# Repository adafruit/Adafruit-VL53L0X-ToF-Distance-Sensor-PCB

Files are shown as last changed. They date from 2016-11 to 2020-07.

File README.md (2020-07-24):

# PCB files for the Adafruit VL53L0X ToF Distance Sensor

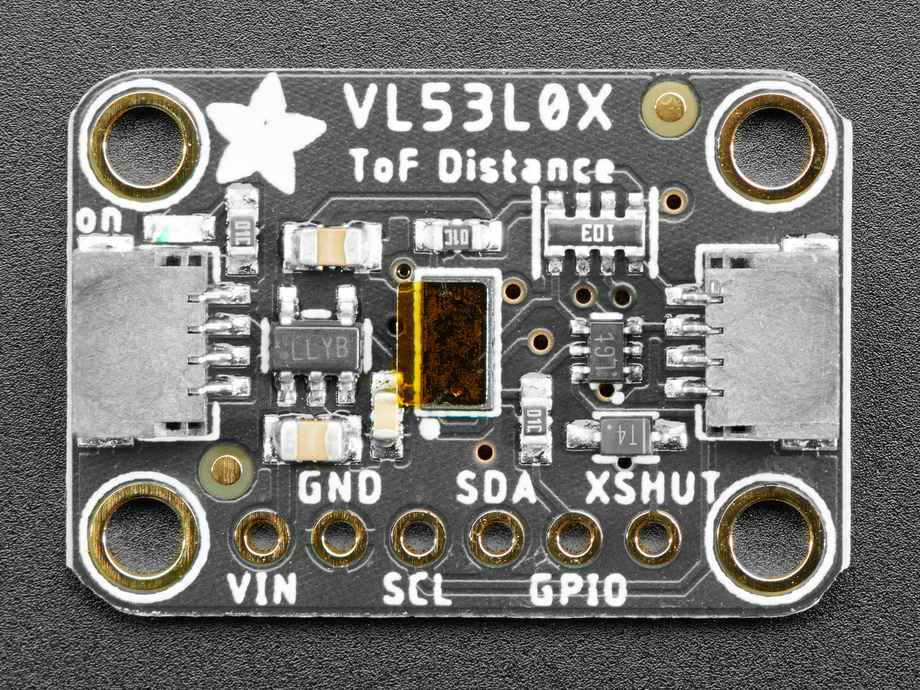
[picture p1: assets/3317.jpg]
<a href="http://www.adafruit.com/products/3317"><br/></a>
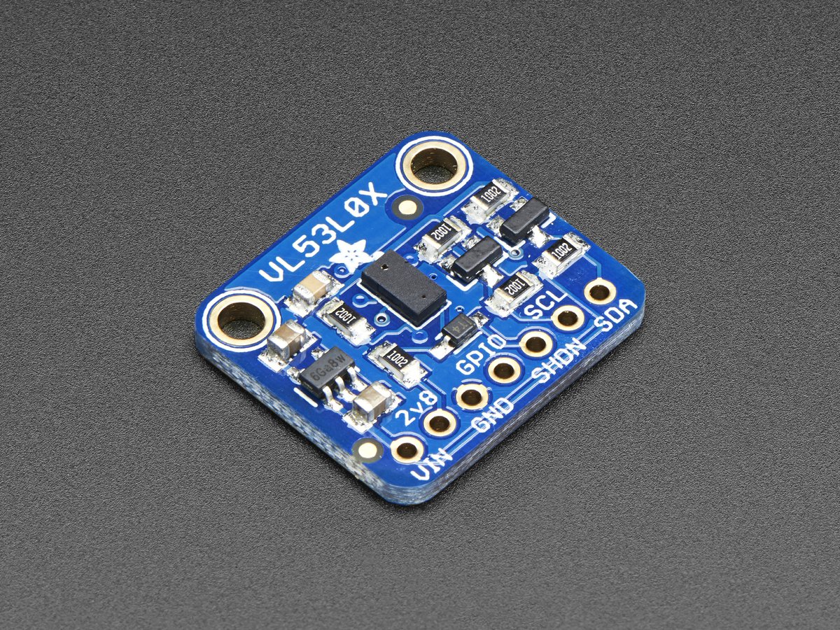
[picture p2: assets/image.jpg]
<a href="http://www.adafruit.com/products/3317"><br/>Click here to purchase one from the Adafruit shop</a>

__Format is EagleCAD schematic and board layout__

The __VL53L0X__ is a *Time of Flight* distance sensor like no other you've used! The sensor contains a very tiny invisible laser source, and a matching sensor. The VL53L0X can detect the "time of flight", or how long the light has taken to bounce back to the sensor. Since it uses a very narrow light source, it is good for determining distance of only the surface directly in front of it. Unlike sonars that bounce ultrasonic waves, the 'cone' of sensing is very narrow. Unlike IR distance sensors that try to measure the amount of light bounced, the VL53L0x is much more precise and doesn't have linearity problems or 'double imaging' where you can't tell if an object is very far or very close.

This is the 'big sister' of the [VL6180X ToF sensor](https://www.adafruit.com/products/3316), and can handle about 50mm to 1200mm of range distance. If you need a smaller/closer range, check out the VL6180X which can measure 5mm to 200mm and also contains a light sensor.

The sensor is small and easy to use in any robotics or interactive project. Since it needs 2.8V power and logic we put the little fellow on a breakout board with a regulator and level shifting. You can use it with any 3-5V power or logic microcontroller with no worries. Each order comes with a small piece of header. Solder the header onto your breakout board with your iron and some solder and wire it up for instant distance-sensing-success!

Communicating to the sensor is done over I2C with an API written by ST, so its not too hard to port it to your favorite microcontroller. We've written a wrapper library for Arduino so you can use it with any of your Arduino-compatible boards.

[Check out our tutorial for code, schematics, diagrams and more!](https://learn.adafruit.com/adafruit-vl53l0x-micro-lidar-distance-sensor-breakout)

## License

Adafruit invests time and resources providing this open source design, 
please support Adafruit and open-source hardware by purchasing 
products from Adafruit!

Designed by Adafruit Industries.  
Creative Commons Attribution, Share-Alike license, check license.txt for more information
All text above must be included in any redistribution

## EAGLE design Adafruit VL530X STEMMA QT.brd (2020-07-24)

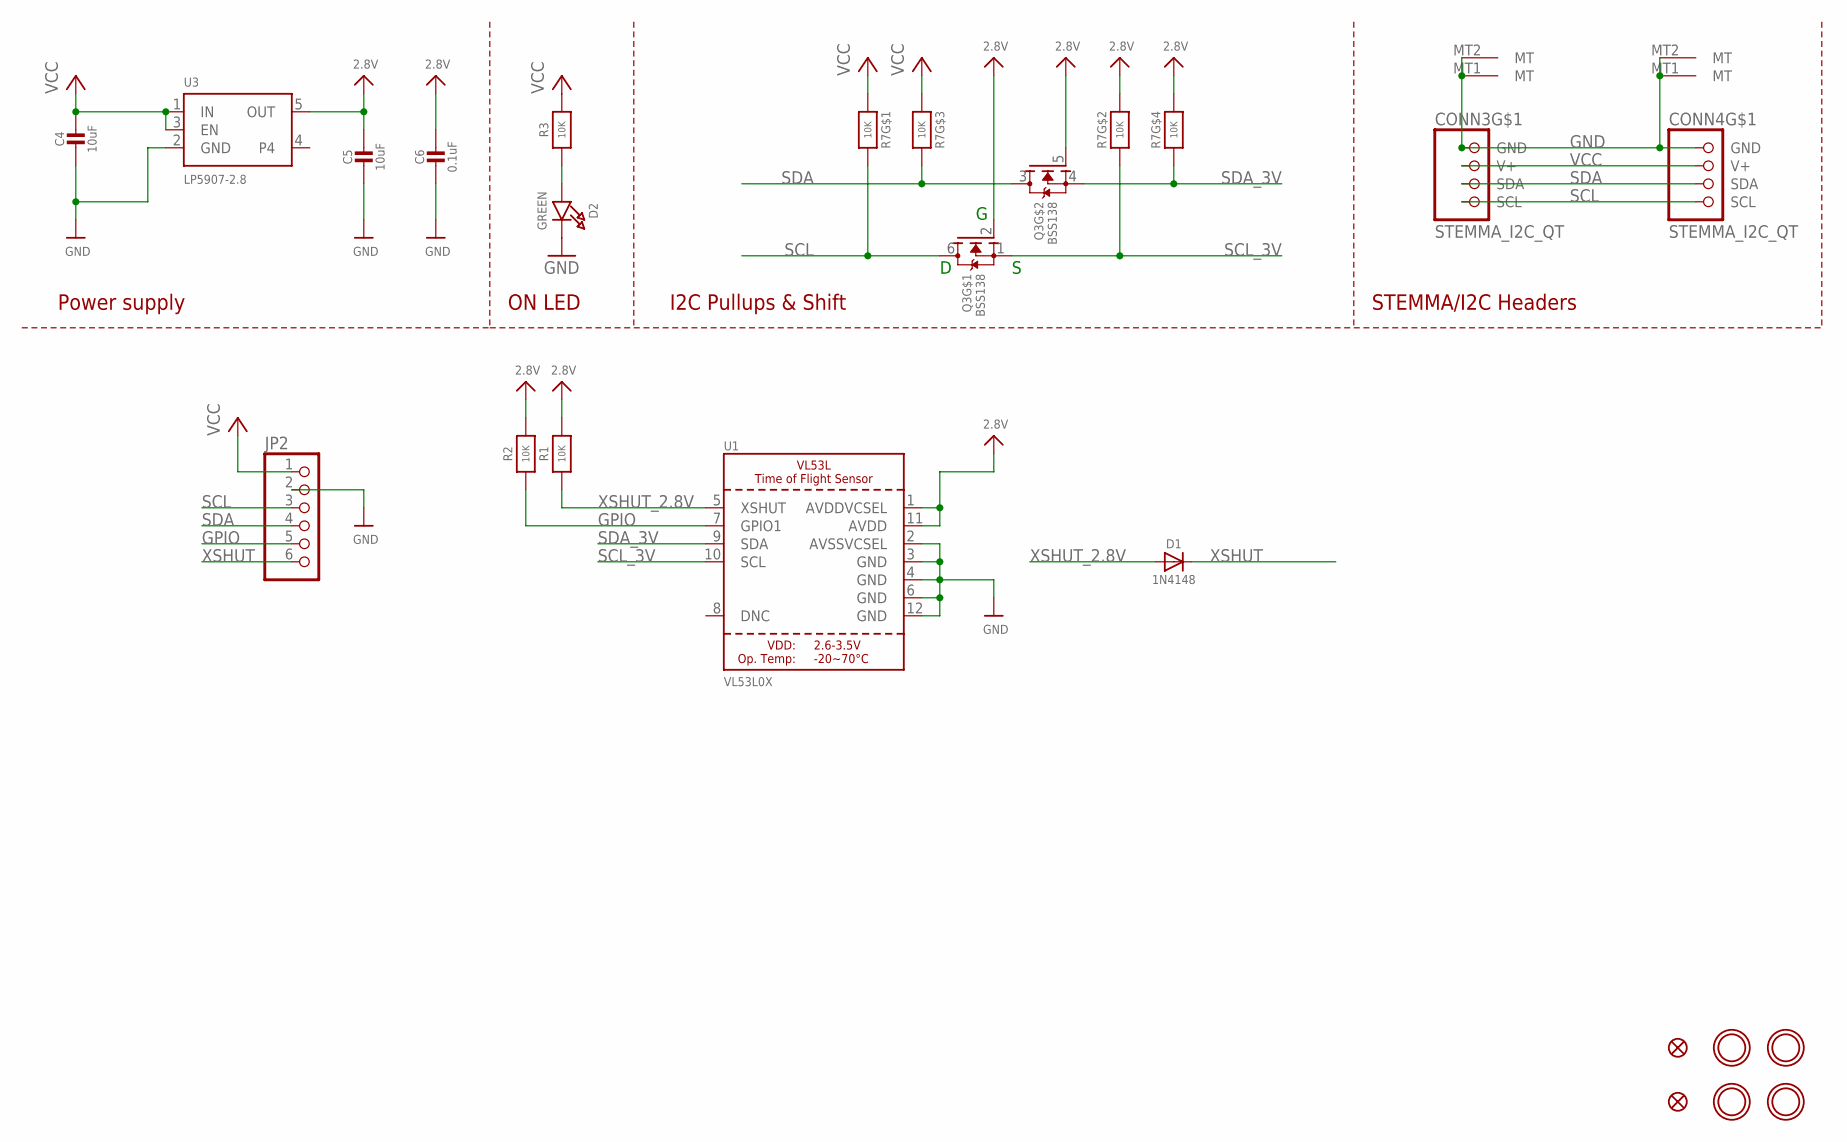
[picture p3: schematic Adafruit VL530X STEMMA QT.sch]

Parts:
C4, C5: 10uF; 0805-NO
C6: 0.1uF; 0603-NO
CONN3, CONN4: STEMMA_I2C_QT; JST_SH4
D1: 1N4148; SOD-323
D2: GREEN; CHIPLED_0603_NOOUTLINE
FID1, FID4: FIDUCIAL_1MM
JP2: HEADER-1X670MIL; 1X06_ROUND_70
Q3: BSS138; SOT363
R1, R2, R3: 10K; 0603-NO
R7: 10K; RESPACK_4X0603
U1: VL53L0X; LGA12_ST
U3: LP5907-2.8; SOT23-5
U$30, U$31, U$33, U$34: MOUNTINGHOLE2.5; MOUNTINGHOLE_2.5_PLATED

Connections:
2.8V: C5.1, C6.1, Q3.2 (G), Q3.5 (G), R1.2, R2.2, R7.2 (1), R7.4 (1), U1.1 (AVDDVCSEL), U1.11 (AVDD), U3.5 (OUT)
GND: C4.2, C5.2, C6.2, CONN3.1 (GND), CONN3.MT1 (MT), CONN3.MT2 (MT), CONN4.1 (GND), CONN4.MT1 (MT), CONN4.MT2 (MT), D2.C, JP2.2, U1.2 (AVSSVCSEL), U1.3 (GND), U1.4 (GND), U1.6 (GND), U1.12 (GND), U3.2 (GND)
GPIO: JP2.5, R2.1, U1.7 (GPIO1)
unnamed: D2.A, R3.1
SCL: CONN3.4 (SCL), CONN4.4 (SCL), JP2.3, Q3.6 (D), R7.8 (2)
SCL_3V: Q3.1 (S), R7.7 (2), U1.10 (SCL)
SDA: CONN3.3 (SDA), CONN4.3 (SDA), JP2.4, Q3.3 (D), R7.6 (2)
SDA_3V: Q3.4 (S), R7.5 (2), U1.9 (SDA)
VCC: C4.1, CONN3.2 (V+), CONN4.2 (V+), JP2.1, R3.2, R7.1, R7.3 (1), U3.1 (IN), U3.3 (EN)
XSHUT: D1.C, JP2.6
XSHUT_2.8V: D1.A, R1.1, U1.5 (XSHUT)

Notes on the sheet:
I2C Pullups & Shift
STEMMA/I2C Headers
ON LED
Power supply

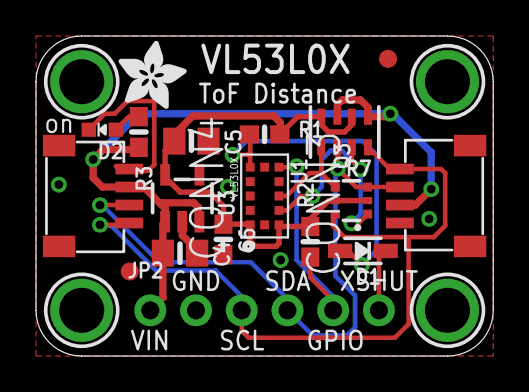
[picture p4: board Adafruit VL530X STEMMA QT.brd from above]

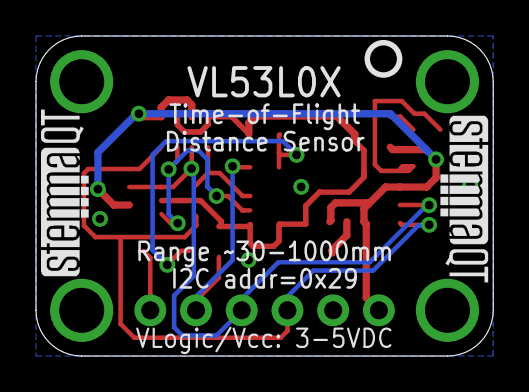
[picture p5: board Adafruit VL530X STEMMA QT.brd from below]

Board: 2 copper layers, 25.4 x 17.8 mm, 25 parts (3 on the bottom side), 11 nets.

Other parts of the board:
U$36: ADAFRUIT_3.5MM
U$37: PCBFEAT-REV-040
U$38, U$39: STEMMAQT

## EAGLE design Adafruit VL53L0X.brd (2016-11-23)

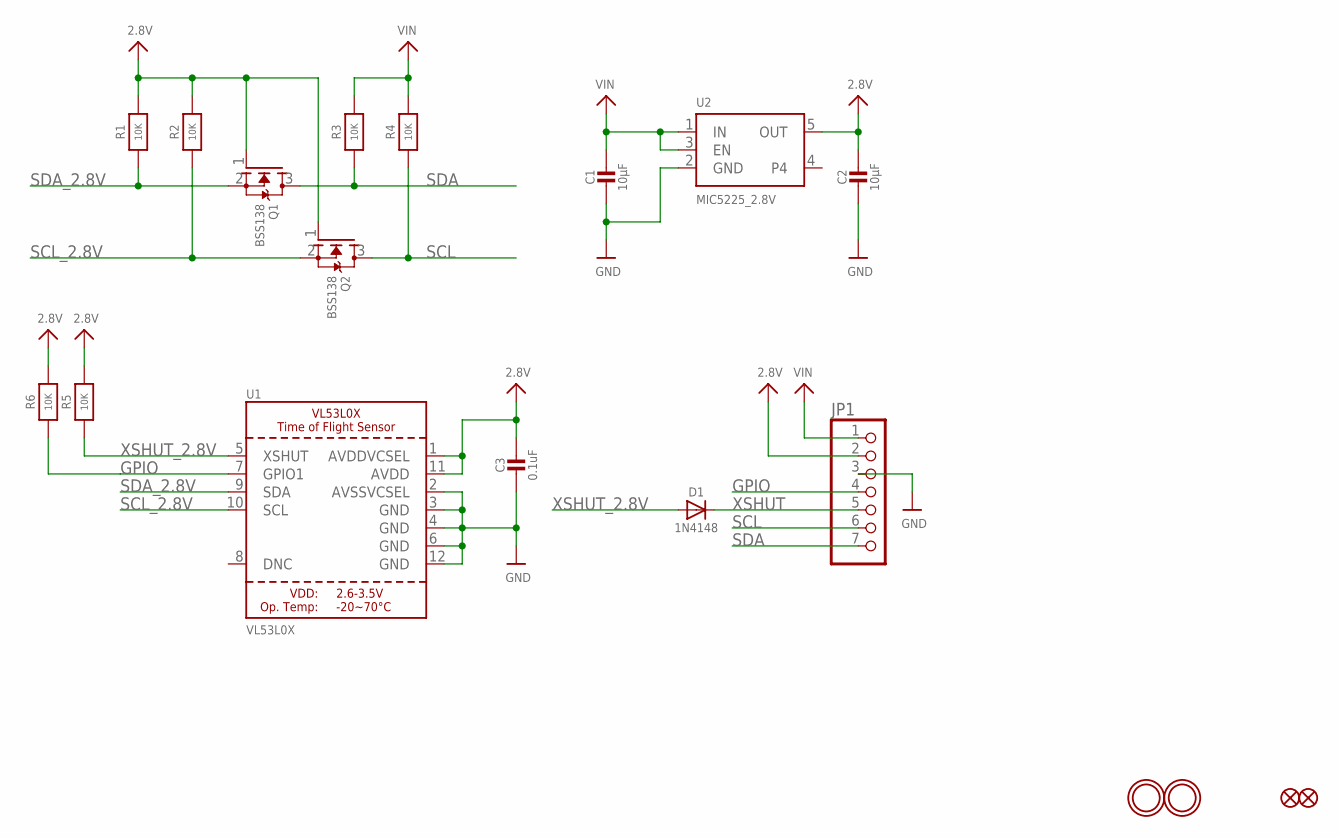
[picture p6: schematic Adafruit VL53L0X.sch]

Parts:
C1, C2: 10µF; 0805-NO
C3: 0.1uF; 0805-NO
D1: 1N4148; SOD-323
FID2, FID3: FIDUCIAL""; FIDUCIAL_1MM
JP1: HEADER-1X770MIL; 1X07_ROUND_70
Q1, Q2: BSS138; SOT23-WIDE
R1, R2, R3, R4, R5, R6: 10K; 0805-NO
U1: VL53L0X; LGA12_ST
U2: MIC5225_2.8V; SOT23-5
U$13, U$14: MOUNTINGHOLE2.5; MOUNTINGHOLE_2.5_PLATED

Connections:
2.8V: C2.1, C3.1, JP1.2, Q1.1 (G), Q2.1 (G), R1.2, R2.2, R5.2, R6.2, U1.1 (AVDDVCSEL), U1.11 (AVDD), U2.5 (OUT)
GND: C1.2, C2.2, C3.2, JP1.3, U1.2 (AVSSVCSEL), U1.3 (GND), U1.4 (GND), U1.6 (GND), U1.12 (GND), U2.2 (GND)
GPIO: JP1.4, R6.1, U1.7 (GPIO1)
SCL: JP1.6, Q2.3 (D), R4.1
SCL_2.8V: Q2.2 (S), R2.1, U1.10 (SCL)
SDA: JP1.7, Q1.3 (D), R3.1
SDA_2.8V: Q1.2 (S), R1.1, U1.9 (SDA)
VIN: C1.1, JP1.1, R3.2, R4.2, U2.1 (IN), U2.3 (EN)
XSHUT: D1.C, JP1.5
XSHUT_2.8V: D1.A, R5.1, U1.5 (XSHUT)

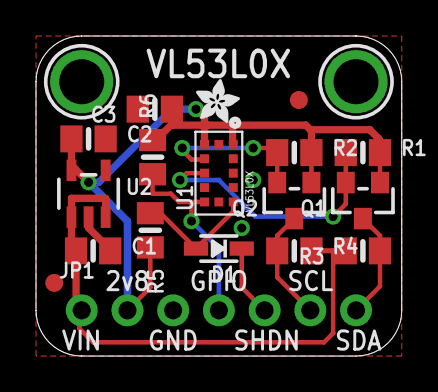
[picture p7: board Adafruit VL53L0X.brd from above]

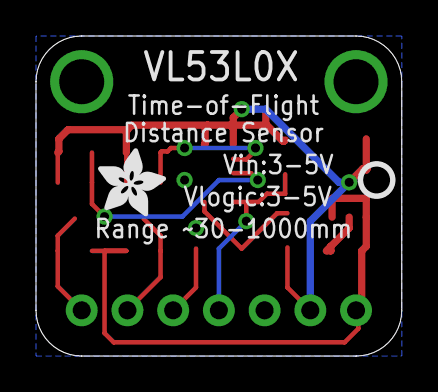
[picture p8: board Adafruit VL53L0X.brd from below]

Board: 2 copper layers, 20.3 x 17.8 mm, 22 parts (2 on the bottom side), 10 nets.

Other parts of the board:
U$12: PCBFEAT-REV-040
U$15: ADAFRUIT_3.5MM
U$18: ADAFRUIT_2.5MM

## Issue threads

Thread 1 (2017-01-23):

Footprint for VL53L0X?

LukeL99, 2017-01-23:
I'm implementing a custom design using the VL53L0X, and I can't find a footprint to use for it. I checked your design, and saw it was referenced from the microbuilder library, but I can't find it in the version of the microbuilder library I found online, nor in the Adafruit eagle library. Can you provide the part definition files somewhere?

Thanks!

ladyada, 2017-01-23:
try http://slopjong.de/2012/12/06/eagle-extract-a-symbol-from-a-project-to-a-library/ !

LukeL99, 2017-01-23:
Didn't know you could do that - worked great. Thanks for the fast response!

For anyone trying to do this in the future, open the board or schematic, and navigate to:

File > Export > Libraries

The ULP will only give you the footprint or the symbol, depending on whether you're on schematic or layout. Exporting will give you the full libraries.

Closed 2017-01-23.

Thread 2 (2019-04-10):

Typo in the reference to product page.

AlvaroHermida, 2019-04-10:
The reference should be:
https://www.adafruit.com/product/3317
instead of the current:
https://www.adafruit.com/product/3177

ladyada, 2019-04-10:
@hoffmanjan

hoffmannjan, 2019-05-15:
https://github.com/adafruit/Adafruit-VL53L0X-ToF-Distance-Sensor-PCB/pull/4

added readme + image + requested URL fix + license, please close when merged

ladyada, 2019-05-15:
we cleaned this repo :)

Closed 2019-05-15.

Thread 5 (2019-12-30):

False triggers in sunlight

bill-orange, 2019-12-30:
I am using the VL53LOX as a 'car position detector' in my garage.  If nothing is in range of the sensor an LED is off.  If the car is 30" to 40" from the rear wall the LED is on solid.  Closer than 30" and the LED blinks.  Each state times out in 15 sec. to an LED off state.  Loop has a 60 ms delay at the end.

All is well when the garage door is closed.  When it is open the LED flickers as random IR hits the sensor.

By hardware or software, is there a way to eliminate this annoyance?

kemalcan2, 2021-03-28:
Hello, bill-orange

Did you solve this problem?

Best Regards.

bill-orange, 2021-03-29:
No. Friends have speculated that the sensor is triggering on dust in the air.  This is possible.  Reflected light from the street could be another cause.  Either in hardware or software there needs to be better anti-aliasing, whatever the cause.

kemalcan2, 2021-03-29:
Okay Bill, thank you for your answer.

Take care.

marciogsc, 2021-09-02:
On the ST forum it says that in sunlight the sensor works up to 50 cm.

[https://community.st.com/s/question/0D50X00009XkYI8SAN/vl53l0x-ambient-light-sensitivity](url)

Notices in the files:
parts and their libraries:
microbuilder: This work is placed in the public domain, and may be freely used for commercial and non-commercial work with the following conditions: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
